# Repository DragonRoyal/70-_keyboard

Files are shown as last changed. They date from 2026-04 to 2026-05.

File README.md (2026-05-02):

# 70% keyboard

A low profile sleek 70% keyboard.



## Features
- **Hot Swappable**: Swap existing switches easily without needing to solder
- **LED**: Supports independently controlled RGB backlighting for each switch
- **Multi-Layered**: Work between multiple different layers for increased macros and switch options
- **TFT Screen**: A powerful and sharp TFT display 
- **Raspberry Pi**: Fast and dynamic microcontroller allowing for easy software customization
- **Rotary Encoder**: Easy to use knob for changing granular control such as volume, brightness etc

## CAD




## PCB 






> Firmware is coded in C using the QMK library

## BOM
|Type |Qty|Value |Exclude from BOM|Exclude from Board|Footprint |Price (with tax)|links |
|---|---|---|---|---|---|---|---|
|Microcontroller |1  |RaspberryPi_Pico |FALSE |FALSE |Module:RaspberryPi_Pico_Common_Unspecified |$4 | self-sourced |
|Diode |79 |Diode 14B |FALSE |FALSE |Diode_SMD:D_SOD-123 |$15 | https://www.amazon.com/gp/product/B089KD46P6/ref=ox_sc_act_title_8?smid=A1K2H0ANPH97NN&psc=1 |
|Led |78 |WS2812B |FALSE |FALSE |PCM_marbastlib-various:SK6812 Mini-E Leds |$6 | self-sourced |
|Rotary Encoder |1  |EC11 Rotary Encoder |FALSE |FALSE |Rotary_Encoder:RotaryEncoder_Alps_EC11E-Switch_Vertical_H20mm|$3 | self sourced |
|Switch |78 |Gateroen banana low profile |FALSE |FALSE |PCM_marbastlib-xp-gateron_lp:SW_KS33_HS_KS-2P02B01-02_HS_1u  |$35 | self sourced |
|Screen |1  |1.47in TFT screen |TRUE |FALSE |PCM_marbastlib-various:1.47IN TFT_SCREEN | 7 | self sourced |
|Level Converter |1  |3.3V 5V Level Shifter |FALSE |FALSE |PCM_marbastlib-various:level_shifter |7 | self sourced |
|3D printed parts (plate+case)|1  |PLA filament 500g |TRUE |FALSE |None | 10 | self sourced |
|Key Caps |78 |Key Cap set |TRUE |TRUE |NONE | 13 | https://www.amazon.com/GMKWTL-Keyboard-Compatiability-Mechanical-Keyboard/dp/B0DHZSBBGN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|
|Hot Swap pieces |78 |Pieces to enable hotswapping|FALSE |FALSE |None |$13 | https://www.amazon.com/DUROCK-Mechanical-Keyboard-Switches-Hot-Swap/dp/B0B4W9YMGM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 |
|PCB Board |1  |Pcb from JLCPCB |FALSE |FALSE | |$35 | https://jlcpcb.com/ |

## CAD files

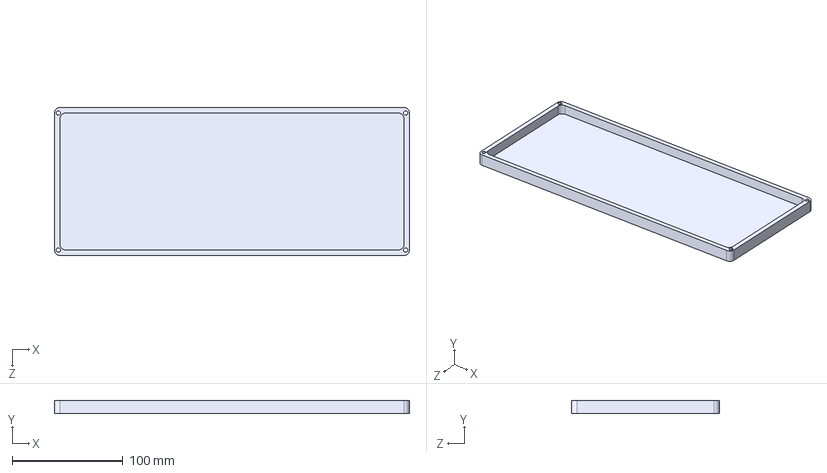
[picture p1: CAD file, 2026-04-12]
cad/bot_case.STEP
320.5 x 12.0 x 133.7 mm

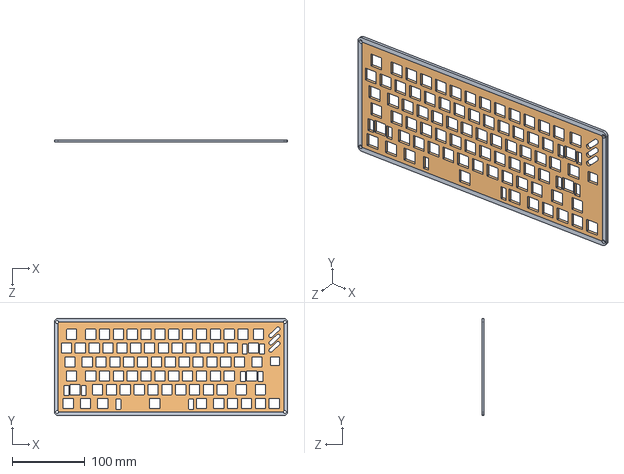
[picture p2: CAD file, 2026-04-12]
cad/top_v3.STEP
320.5 x 133.7 x 3.00 mm

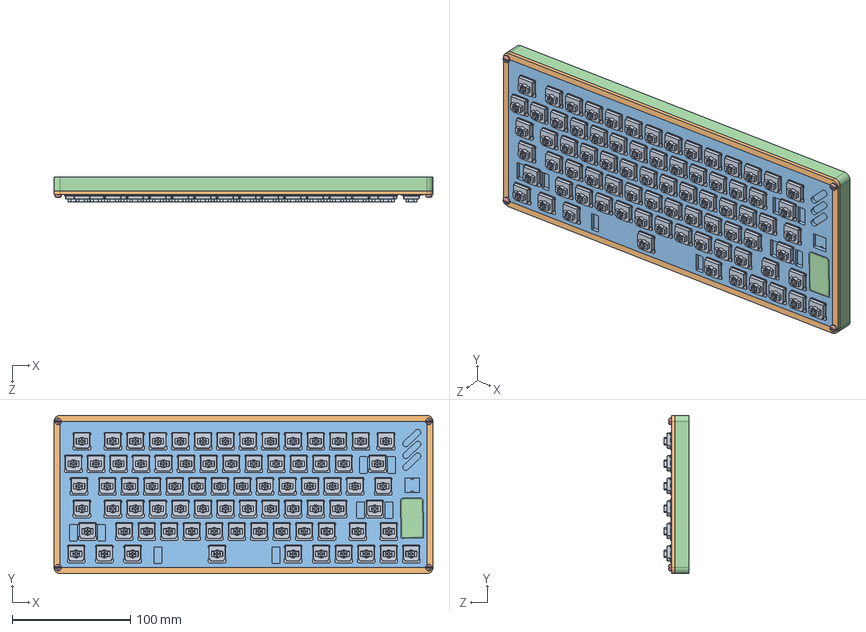
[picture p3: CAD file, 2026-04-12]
cad/75_assem.STEP
320.5 x 133.7 x 21.1 mm
case_v3
bot_case
75% keyboard 1.2.1.step x 78
RaspberryPi_Pico_Module_KiCad.step
HS_KS-2P02B01-02_KS33.step x 78
4960.step x 78
D_SOD-123.step x 79
75% keyboard_PCB.step
screen
pan head tapping screw_am_PHT 3x13x12-slot-T-N x 4

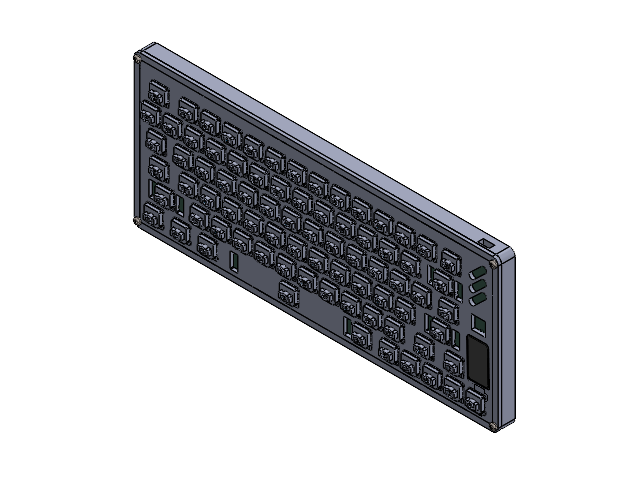
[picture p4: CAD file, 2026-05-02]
cad/solidwork_src/70_assem.SLDASM
case_v3
bot_case
75% keyboard 1.2.1.step x 78
RaspberryPi_Pico_Module_KiCad.step
HS_KS-2P02B01-02_KS33.step x 78
4960.step x 78
D_SOD-123.step x 79
75% keyboard_PCB.step
screen
pan head tapping screw_am x 4

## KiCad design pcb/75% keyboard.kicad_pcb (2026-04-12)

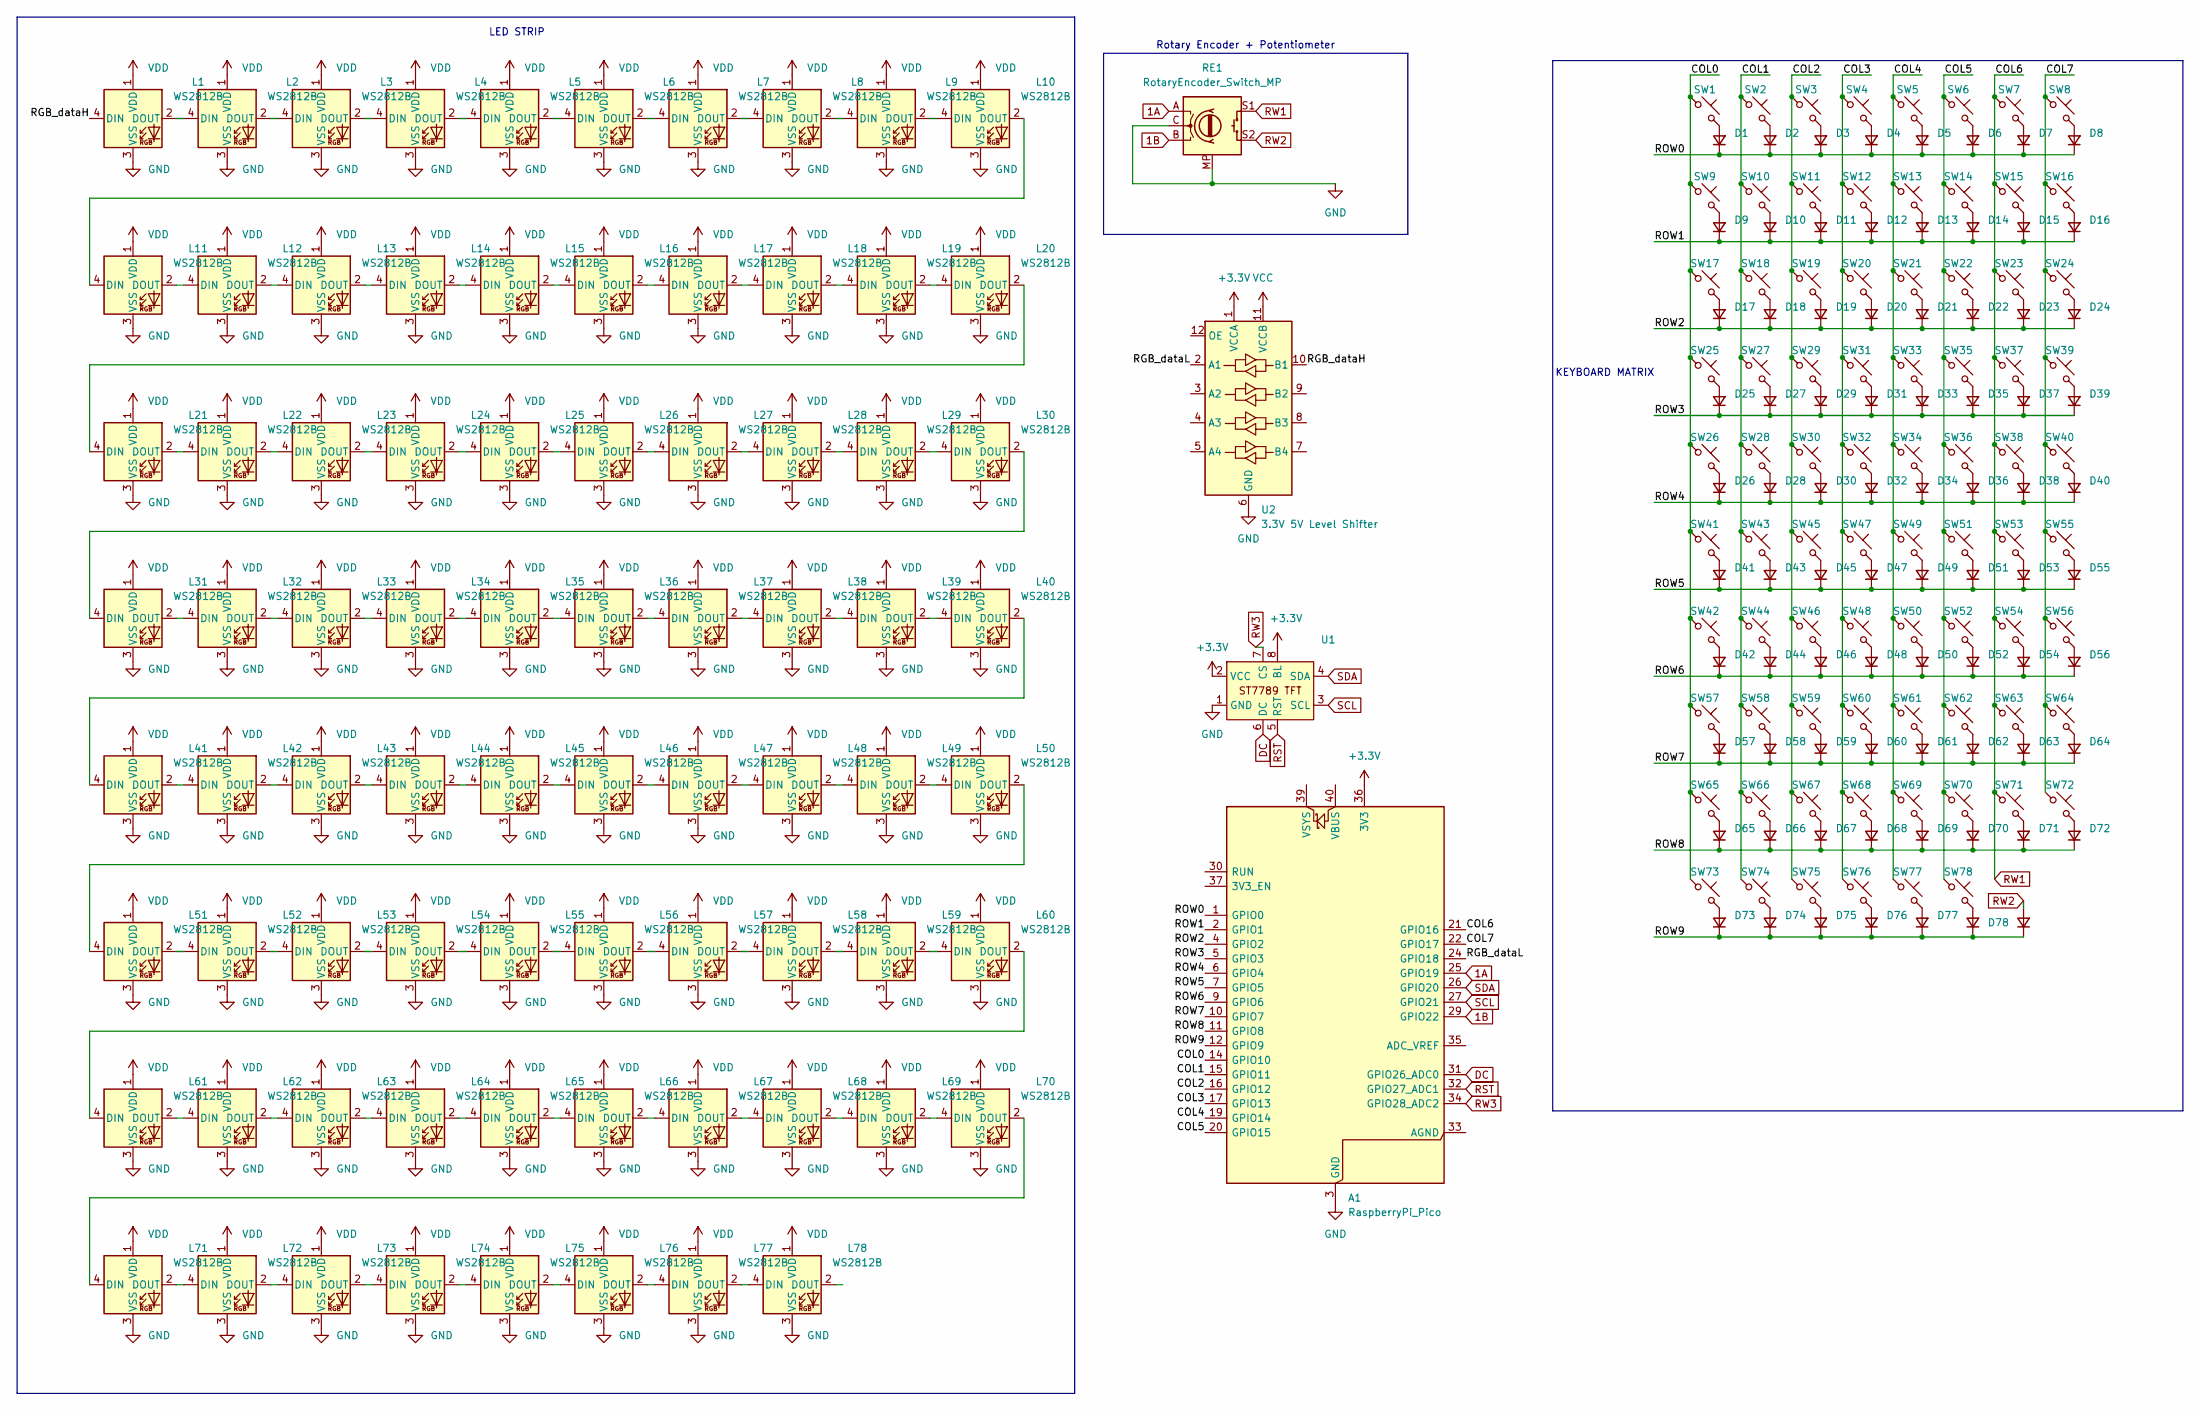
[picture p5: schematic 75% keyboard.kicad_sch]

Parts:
A1: RaspberryPi_Pico; RaspberryPi_Pico_Common_Unspecified
D1, D2, D3, D4, D5, D6, D7, D8, D9, D10, D11, D12, D13, D14, D15, D16, D17, D18, D19, D20, D21, D22, D23, D24, D25, D26, D27, D28, D29, D30, D31, D32, D33, D34, D35, D36, D37, D38, D39, D40, D41, D42, D43, D44, D45, D46, D47, D48, D49, D50, D51, D52, D53, D54, D55, D56, D57, D58, D59, D60, D61, D62, D63, D64, D65, D66, D67, D68, D69, D70, D71, D72, D73, D74, D75, D76, D77, D78, D79: D_Small; D_SOD-123
L1, L2, L3, L4, L5, L6, L7, L8, L9, L10, L11, L12, L13, L14, L15, L16, L17, L18, L19, L20, L21, L22, L23, L24, L25, L26, L27, L28, L29, L30, L31, L32, L33, L34, L35, L36, L37, L38, L39, L40, L41, L42, L43, L44, L45, L46, L47, L48, L49, L50, L51, L52, L53, L54, L55, L56, L57, L58, L59, L60, L61, L62, L63, L64, L65, L66, L67, L68, L69, L70, L71, L72, L73, L74, L75, L76, L77, L78: WS2812B; SK6812 Mini-E Leds
RE1: RotaryEncoder_Switch_MP; RotaryEncoder_Alps_EC11E-Switch_Vertical_H20mm
SW1, SW2, SW3, SW4, SW5, SW6, SW7, SW8, SW9, SW10, SW11, SW12, SW13, SW14, SW15, SW16, SW17, SW18, SW19, SW20, SW21, SW22, SW23, SW24, SW25, SW26, SW27, SW28, SW29, SW30, SW31, SW32, SW33, SW34, SW35, SW36, SW37, SW38, SW39, SW40, SW41, SW42, SW43, SW44, SW45, SW46, SW47, SW48, SW49, SW50, SW51, SW52, SW53, SW54, SW55, SW56, SW57, SW58, SW59, SW60, SW61, SW62, SW63, SW64, SW65, SW66, SW67, SW68, SW69, SW70, SW71, SW72, SW73, SW74, SW75, SW76, SW77, SW78: SW_Push_45deg; SW_KS33_HS_KS-2P02B01-02_HS_1u
U1: 1.47IN TFT_SCREEN
U2: 3.3V 5V Level Shifter; level_shifter

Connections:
1A: A1.25 (GPIO19), RE1.A
1B: A1.29 (GPIO22), RE1.B
+3.3V: A1.36 (3V3), U1.2 (VCC), U1.8 (BL), U2.1 (VCCA); also elsewhere on the board
/COL0: A1.14 (GPIO10), SW1.1, SW9.1, SW17.1, SW25.1, SW26.1, SW41.1, SW42.1, SW57.1, SW65.1, SW73.1
/COL1: A1.15 (GPIO11), SW2.1, SW10.1, SW18.1, SW27.1, SW28.1, SW43.1, SW44.1, SW58.1, SW66.1, SW74.1
/COL2: A1.16 (GPIO12), SW3.1, SW11.1, SW19.1, SW29.1, SW30.1, SW45.1, SW46.1, SW59.1, SW67.1, SW75.1
/COL3: A1.17 (GPIO13), SW4.1, SW12.1, SW20.1, SW31.1, SW32.1, SW47.1, SW48.1, SW60.1, SW68.1, SW76.1
/COL4: A1.19 (GPIO14), SW5.1, SW13.1, SW21.1, SW33.1, SW34.1, SW49.1, SW50.1, SW61.1, SW69.1, SW77.1
/COL5: A1.20 (GPIO15), SW6.1, SW14.1, SW22.1, SW35.1, SW36.1, SW51.1, SW52.1, SW62.1, SW70.1, SW78.1
/COL7: A1.22 (GPIO17), SW8.1, SW16.1, SW24.1, SW39.1, SW40.1, SW55.1, SW56.1, SW64.1, SW72.1
/RGB_dataH: L1.4 (DIN), U2.10 (B1)
/RGB_dataL: A1.24 (GPIO18), U2.2 (A1)
/ROW0: A1.1 (GPIO0), D1.1 (K), D2.1 (K), D3.1 (K), D4.1 (K), D5.1 (K), D6.1 (K), D7.1 (K), D8.1 (K)
/ROW1: A1.2 (GPIO1), D9.1 (K), D10.1 (K), D11.1 (K), D12.1 (K), D13.1 (K), D14.1 (K), D15.1 (K), D16.1 (K)
/ROW2: A1.4 (GPIO2), D17.1 (K), D18.1 (K), D19.1 (K), D20.1 (K), D21.1 (K), D22.1 (K), D23.1 (K), D24.1 (K)
/ROW3: A1.5 (GPIO3), D25.1 (K), D27.1 (K), D29.1 (K), D31.1 (K), D33.1 (K), D35.1 (K), D37.1 (K), D39.1 (K)
/ROW4: A1.6 (GPIO4), D26.1 (K), D28.1 (K), D30.1 (K), D32.1 (K), D34.1 (K), D36.1 (K), D38.1 (K), D40.1 (K)
/ROW5: A1.7 (GPIO5), D41.1 (K), D43.1 (K), D45.1 (K), D47.1 (K), D49.1 (K), D51.1 (K), D53.1 (K), D55.1 (K)
/ROW6: A1.9 (GPIO6), D42.1 (K), D44.1 (K), D46.1 (K), D48.1 (K), D50.1 (K), D52.1 (K), D54.1 (K), D56.1 (K)
/ROW7: A1.10 (GPIO7), D57.1 (K), D58.1 (K), D59.1 (K), D60.1 (K), D61.1 (K), D62.1 (K), D63.1 (K), D64.1 (K)
/ROW8: A1.11 (GPIO8), D65.1 (K), D66.1 (K), D67.1 (K), D68.1 (K), D69.1 (K), D70.1 (K), D71.1 (K), D72.1 (K)
/ROW9: A1.12 (GPIO9), D73.1 (K), D74.1 (K), D75.1 (K), D76.1 (K), D77.1 (K), D78.1 (K), D79.1 (K)
DC: A1.31 (GPIO26_ADC0), U1.6 (DC)
GND: A1.3 (GND), A1.8 (GND), A1.13 (GND), A1.18 (GND), A1.23 (GND), A1.28 (GND), A1.38 (GND), L1.3 (VSS), L2.3 (VSS), L3.3 (VSS), L4.3 (VSS), L5.3 (VSS), L6.3 (VSS), L7.3 (VSS), L8.3 (VSS), L9.3 (VSS), L10.3 (VSS), L11.3 (VSS), L12.3 (VSS), L13.3 (VSS), L14.3 (VSS), L15.3 (VSS), L16.3 (VSS), L17.3 (VSS), L18.3 (VSS), L19.3 (VSS), L20.3 (VSS), L21.3 (VSS), L22.3 (VSS), L23.3 (VSS), L24.3 (VSS), L25.3 (VSS), L26.3 (VSS), L27.3 (VSS), L28.3 (VSS), L29.3 (VSS), L30.3 (VSS), L31.3 (VSS), L32.3 (VSS), L33.3 (VSS), L34.3 (VSS), L35.3 (VSS), L36.3 (VSS), L37.3 (VSS), L38.3 (VSS), L39.3 (VSS), L40.3 (VSS), L41.3 (VSS), L42.3 (VSS), L43.3 (VSS), L44.3 (VSS), L45.3 (VSS), L46.3 (VSS), L47.3 (VSS), L48.3 (VSS), L49.3 (VSS), L50.3 (VSS), L51.3 (VSS), L52.3 (VSS), L53.3 (VSS), L54.3 (VSS), L55.3 (VSS), L56.3 (VSS), L57.3 (VSS), L58.3 (VSS), L59.3 (VSS), L60.3 (VSS), L61.3 (VSS), L62.3 (VSS), L63.3 (VSS), L64.3 (VSS), L65.3 (VSS), L66.3 (VSS), L67.3 (VSS), L68.3 (VSS), L69.3 (VSS), L70.3 (VSS), L71.3 (VSS), L72.3 (VSS), L73.3 (VSS), L74.3 (VSS), L75.3 (VSS), L76.3 (VSS), L77.3 (VSS), L78.3 (VSS), RE1.C, RE1.MP, U1.1 (GND), U2.6 (GND); also elsewhere on the board
unnamed: D1.2 (A), SW1.2
unnamed: D2.2 (A), SW2.2
unnamed: D3.2 (A), SW3.2
unnamed: D4.2 (A), SW4.2
unnamed: D5.2 (A), SW5.2
unnamed: D6.2 (A), SW6.2
unnamed: D7.2 (A), SW7.2
unnamed: D8.2 (A), SW8.2
unnamed: D9.2 (A), SW9.2
unnamed: D10.2 (A), SW10.2
unnamed: D11.2 (A), SW11.2
unnamed: D12.2 (A), SW12.2
unnamed: D13.2 (A), SW13.2
unnamed: D14.2 (A), SW14.2
unnamed: D15.2 (A), SW15.2
unnamed: D16.2 (A), SW16.2
unnamed: D17.2 (A), SW17.2
unnamed: D18.2 (A), SW18.2
unnamed: D19.2 (A), SW19.2
unnamed: D20.2 (A), SW20.2
unnamed: D21.2 (A), SW21.2
unnamed: D22.2 (A), SW22.2
unnamed: D23.2 (A), SW23.2
unnamed: D24.2 (A), SW24.2
unnamed: D25.2 (A), SW25.2
unnamed: D26.2 (A), SW26.2
unnamed: D27.2 (A), SW27.2
unnamed: D28.2 (A), SW28.2
unnamed: D29.2 (A), SW29.2
unnamed: D30.2 (A), SW30.2
unnamed: D31.2 (A), SW31.2
unnamed: D32.2 (A), SW32.2
unnamed: D33.2 (A), SW33.2
unnamed: D34.2 (A), SW34.2
unnamed: D35.2 (A), SW35.2
unnamed: D36.2 (A), SW36.2
unnamed: D37.2 (A), SW37.2
unnamed: D38.2 (A), SW38.2
unnamed: D39.2 (A), SW39.2
unnamed: D40.2 (A), SW40.2
unnamed: D41.2 (A), SW41.2
unnamed: D42.2 (A), SW42.2
unnamed: D43.2 (A), SW43.2
unnamed: D44.2 (A), SW44.2
unnamed: D45.2 (A), SW45.2
unnamed: D46.2 (A), SW46.2
unnamed: D47.2 (A), SW47.2
unnamed: D48.2 (A), SW48.2
unnamed: D49.2 (A), SW49.2
unnamed: D50.2 (A), SW50.2
unnamed: D51.2 (A), SW51.2
unnamed: D52.2 (A), SW52.2
unnamed: D53.2 (A), SW53.2
unnamed: D54.2 (A), SW54.2
unnamed: D55.2 (A), SW55.2
unnamed: D56.2 (A), SW56.2
unnamed: D57.2 (A), SW57.2
unnamed: D58.2 (A), SW58.2
unnamed: D59.2 (A), SW59.2
unnamed: D60.2 (A), SW60.2
unnamed: D61.2 (A), SW61.2
unnamed: D62.2 (A), SW62.2
unnamed: D63.2 (A), SW63.2
unnamed: D64.2 (A), SW64.2
unnamed: D65.2 (A), SW65.2
unnamed: D66.2 (A), SW66.2
unnamed: D67.2 (A), SW67.2
unnamed: D68.2 (A), SW68.2
unnamed: D69.2 (A), SW69.2
unnamed: D70.2 (A), SW70.2
unnamed: D71.2 (A), SW71.2
unnamed: D72.2 (A), SW72.2
unnamed: D73.2 (A), SW73.2
unnamed: D74.2 (A), SW74.2
unnamed: D75.2 (A), SW75.2
unnamed: D76.2 (A), SW76.2
unnamed: D77.2 (A), SW77.2
unnamed: D78.2 (A), SW78.2
unnamed: L1.2 (DOUT), L2.4 (DIN)
unnamed: L2.2 (DOUT), L3.4 (DIN)
unnamed: L3.2 (DOUT), L4.4 (DIN)
unnamed: L4.2 (DOUT), L5.4 (DIN)
unnamed: L5.2 (DOUT), L6.4 (DIN)
unnamed: L6.2 (DOUT), L7.4 (DIN)
unnamed: L7.2 (DOUT), L8.4 (DIN)
unnamed: L8.2 (DOUT), L9.4 (DIN)
unnamed: L9.2 (DOUT), L10.4 (DIN)
unnamed: L10.2 (DOUT), L11.4 (DIN)
unnamed: L11.2 (DOUT), L12.4 (DIN)
unnamed: L12.2 (DOUT), L13.4 (DIN)
unnamed: L13.2 (DOUT), L14.4 (DIN)
unnamed: L14.2 (DOUT), L15.4 (DIN)
unnamed: L15.2 (DOUT), L16.4 (DIN)
unnamed: L16.2 (DOUT), L17.4 (DIN)
unnamed: L17.2 (DOUT), L18.4 (DIN)
unnamed: L18.2 (DOUT), L19.4 (DIN)
unnamed: L19.2 (DOUT), L20.4 (DIN)
unnamed: L20.2 (DOUT), L21.4 (DIN)
unnamed: L21.2 (DOUT), L22.4 (DIN)
unnamed: L22.2 (DOUT), L23.4 (DIN)
unnamed: L23.2 (DOUT), L24.4 (DIN)
unnamed: L24.2 (DOUT), L25.4 (DIN)
unnamed: L25.2 (DOUT), L26.4 (DIN)
unnamed: L26.2 (DOUT), L27.4 (DIN)
unnamed: L27.2 (DOUT), L28.4 (DIN)
unnamed: L28.2 (DOUT), L29.4 (DIN)
unnamed: L29.2 (DOUT), L30.4 (DIN)
unnamed: L30.2 (DOUT), L31.4 (DIN)
unnamed: L31.2 (DOUT), L32.4 (DIN)
unnamed: L32.2 (DOUT), L33.4 (DIN)
unnamed: L33.2 (DOUT), L34.4 (DIN)
unnamed: L34.2 (DOUT), L35.4 (DIN)
unnamed: L35.2 (DOUT), L36.4 (DIN)
unnamed: L36.2 (DOUT), L37.4 (DIN)
unnamed: L37.2 (DOUT), L38.4 (DIN)
unnamed: L38.2 (DOUT), L39.4 (DIN)
unnamed: L39.2 (DOUT), L40.4 (DIN)
unnamed: L40.2 (DOUT), L41.4 (DIN)
unnamed: L41.2 (DOUT), L42.4 (DIN)
unnamed: L42.2 (DOUT), L43.4 (DIN)
unnamed: L43.2 (DOUT), L44.4 (DIN)
unnamed: L44.2 (DOUT), L45.4 (DIN)
unnamed: L45.2 (DOUT), L46.4 (DIN)
unnamed: L46.2 (DOUT), L47.4 (DIN)
unnamed: L47.2 (DOUT), L48.4 (DIN)
unnamed: L48.2 (DOUT), L49.4 (DIN)
unnamed: L49.2 (DOUT), L50.4 (DIN)
unnamed: L50.2 (DOUT), L51.4 (DIN)
unnamed: L51.2 (DOUT), L52.4 (DIN)
unnamed: L52.2 (DOUT), L53.4 (DIN)
unnamed: L53.2 (DOUT), L54.4 (DIN)
unnamed: L54.2 (DOUT), L55.4 (DIN)
unnamed: L55.2 (DOUT), L56.4 (DIN)
unnamed: L56.2 (DOUT), L57.4 (DIN)
unnamed: L57.2 (DOUT), L58.4 (DIN)
unnamed: L58.2 (DOUT), L59.4 (DIN)
unnamed: L59.2 (DOUT), L60.4 (DIN)
unnamed: L60.2 (DOUT), L61.4 (DIN)
unnamed: L61.2 (DOUT), L62.4 (DIN)
unnamed: L62.2 (DOUT), L63.4 (DIN)
unnamed: L63.2 (DOUT), L64.4 (DIN)
unnamed: L64.2 (DOUT), L65.4 (DIN)
unnamed: L65.2 (DOUT), L66.4 (DIN)
unnamed: L66.2 (DOUT), L67.4 (DIN)
unnamed: L67.2 (DOUT), L68.4 (DIN)
unnamed: L68.2 (DOUT), L69.4 (DIN)
unnamed: L69.2 (DOUT), L70.4 (DIN)
unnamed: L70.2 (DOUT), L71.4 (DIN)
unnamed: L71.2 (DOUT), L72.4 (DIN)
unnamed: L72.2 (DOUT), L73.4 (DIN)
unnamed: L73.2 (DOUT), L74.4 (DIN)
unnamed: L74.2 (DOUT), L75.4 (DIN)
unnamed: L75.2 (DOUT), L76.4 (DIN)
unnamed: L76.2 (DOUT), L77.4 (DIN)
unnamed: L77.2 (DOUT), L78.4 (DIN)
RST: A1.32 (GPIO27_ADC1), U1.5 (RST)
RW1: A1.21 (GPIO16), RE1.S1, SW7.1, SW15.1, SW23.1, SW37.1, SW38.1, SW53.1, SW54.1, SW63.1, SW71.1
RW2: D79.2 (A), RE1.S2
RW3: A1.34 (GPIO28_ADC2), U1.7 (CS); also elsewhere on the board
SCL: A1.27 (GPIO21), U1.3 (SCL)
SDA: A1.26 (GPIO20), U1.4 (SDA)
VCC: U2.11 (VCCB)
VDD: L1.1 (VDD), L2.1 (VDD), L3.1 (VDD), L4.1 (VDD), L5.1 (VDD), L6.1 (VDD), L7.1 (VDD), L8.1 (VDD), L9.1 (VDD), L10.1 (VDD), L11.1 (VDD), L12.1 (VDD), L13.1 (VDD), L14.1 (VDD), L15.1 (VDD), L16.1 (VDD), L17.1 (VDD), L18.1 (VDD), L19.1 (VDD), L20.1 (VDD), L21.1 (VDD), L22.1 (VDD), L23.1 (VDD), L24.1 (VDD), L25.1 (VDD), L26.1 (VDD), L27.1 (VDD), L28.1 (VDD), L29.1 (VDD), L30.1 (VDD), L31.1 (VDD), L32.1 (VDD), L33.1 (VDD), L34.1 (VDD), L35.1 (VDD), L36.1 (VDD), L37.1 (VDD), L38.1 (VDD), L39.1 (VDD), L40.1 (VDD), L41.1 (VDD), L42.1 (VDD), L43.1 (VDD), L44.1 (VDD), L45.1 (VDD), L46.1 (VDD), L47.1 (VDD), L48.1 (VDD), L49.1 (VDD), L50.1 (VDD), L51.1 (VDD), L52.1 (VDD), L53.1 (VDD), L54.1 (VDD), L55.1 (VDD), L56.1 (VDD), L57.1 (VDD), L58.1 (VDD), L59.1 (VDD), L60.1 (VDD), L61.1 (VDD), L62.1 (VDD), L63.1 (VDD), L64.1 (VDD), L65.1 (VDD), L66.1 (VDD), L67.1 (VDD), L68.1 (VDD), L69.1 (VDD), L70.1 (VDD), L71.1 (VDD), L72.1 (VDD), L73.1 (VDD), L74.1 (VDD), L75.1 (VDD), L76.1 (VDD), L77.1 (VDD), L78.1 (VDD)

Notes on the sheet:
LED STRIP
Rotary Encoder + Potentiometer
KEYBOARD MATRIX

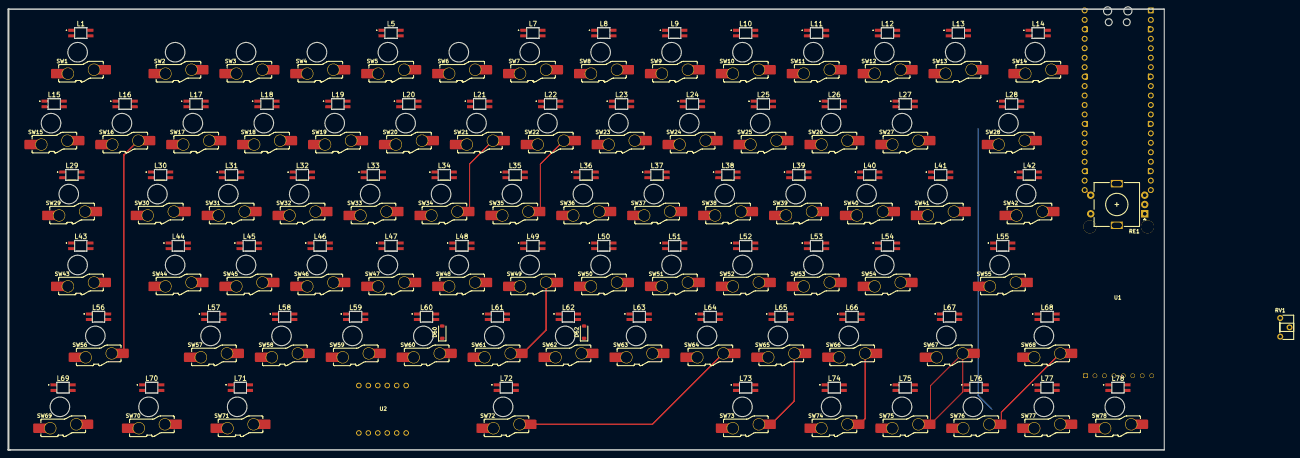
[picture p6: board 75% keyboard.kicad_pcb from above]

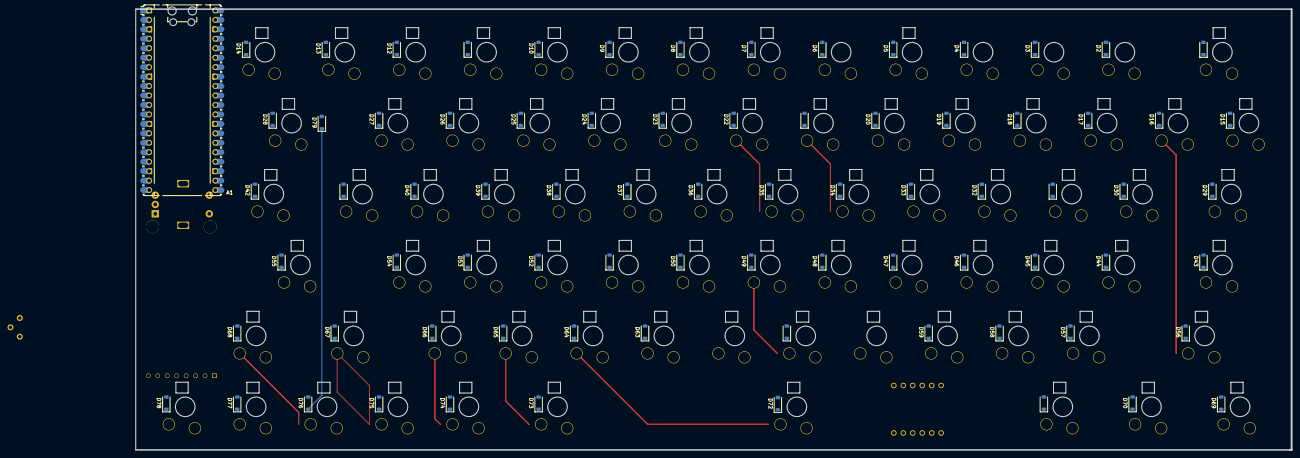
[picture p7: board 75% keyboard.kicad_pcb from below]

Board: 2 copper layers, 310.5 x 118.4 mm, 236 parts (78 on the bottom side), 180 nets.

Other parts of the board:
RV1: R_Potentiometer; Potentiometer_ACP_CA6-H2,5_Horizontal

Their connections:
+3.3V: RV1.1; also elsewhere on the board
GND: RV1.3; also elsewhere on the board
RW3: RV1.2; also elsewhere on the board

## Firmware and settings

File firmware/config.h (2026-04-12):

#ifndef CONFIG_H
#define CONFIG_H

#include "config_common.h"

/* USB Device descriptor parameter */
#define VENDOR_ID       0xFEED
#define PRODUCT_ID      0x6060
#define DEVICE_VER      0x0001
#define MANUFACTURER    qmkbuilder
#define PRODUCT         keyboard
#define DESCRIPTION     Keyboard

/* key matrix size */
#define MATRIX_ROWS 6
#define MATRIX_COLS 16

/* key matrix pins */
#define MATRIX_ROW_PINS { B0, B1, B2, B3, B4, B5 }
#define MATRIX_COL_PINS { B6, B7, C0, C1, C2, C3, C4, C5, C6, C7, D0, D1, D2, D3, D4, D5 }
#define UNUSED_PINS

/* COL2ROW or ROW2COL */
#define DIODE_DIRECTION COL2ROW

/* number of backlight levels */

#ifdef BACKLIGHT_PIN
#define BACKLIGHT_LEVELS 3
#endif

/* Set 0 if debouncing isn't needed */
#define DEBOUNCING_DELAY 5

/* Mechanical locking support. Use KC_LCAP, KC_LNUM or KC_LSCR instead in keymap */
#define LOCKING_SUPPORT_ENABLE

/* Locking resynchronize hack */
#define LOCKING_RESYNC_ENABLE

/* key combination for command */
#define IS_COMMAND() ( \
    keyboard_report->mods == (MOD_BIT(KC_LSHIFT) | MOD_BIT(KC_RSHIFT)) \
)

/* prevent stuck modifiers */
#define PREVENT_STUCK_MODIFIERS


#ifdef RGB_DI_PIN
#define RGBLIGHT_ANIMATIONS
#define RGBLED_NUM 0
#define RGBLIGHT_HUE_STEP 8
#define RGBLIGHT_SAT_STEP 8
#define RGBLIGHT_VAL_STEP 8
#endif

#endif

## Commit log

2026-05-01 Update BOM with additional components and details
    Added new components including microcontroller, diodes, LEDs, rotary encoder, and more to the BOM.
    [70% keyboard-bom.csv]
2026-05-01 Add new BOM image to README
2026-05-02 Update 70% keyboard-bom.csv
    [70% keyboard-bom.csv]
2026-05-02 Fix formatting and sourcing in keyboard BOM
    Added a comma at the end of the Microcontroller line and corrected the sourcing text for Rotary Encoder and Switch.
    [70% keyboard-bom.csv]
